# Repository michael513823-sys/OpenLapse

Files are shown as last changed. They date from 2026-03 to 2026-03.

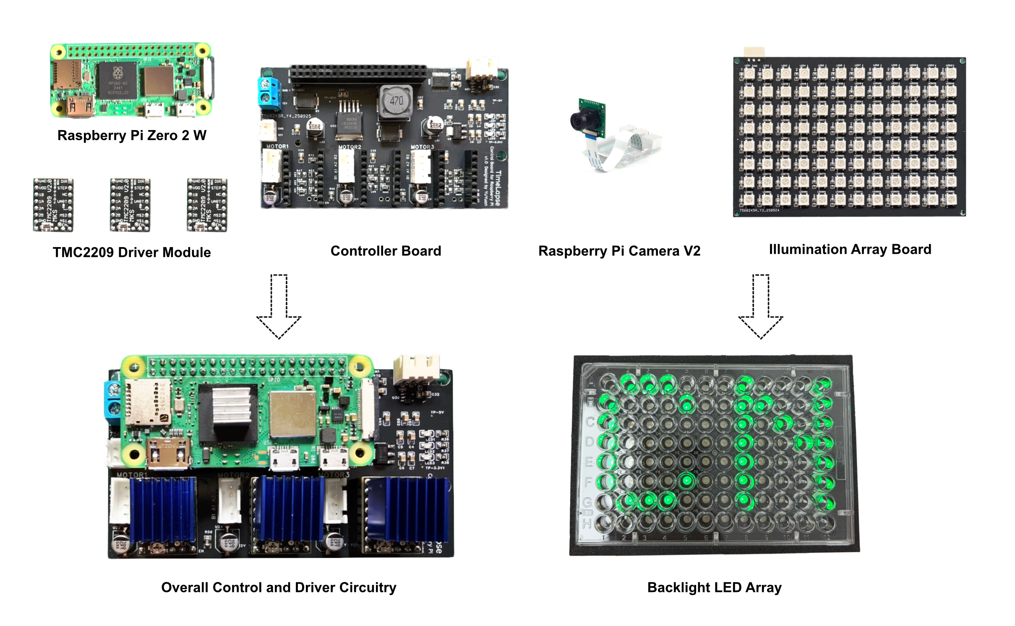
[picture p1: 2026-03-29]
imgs/Figure4.tiff

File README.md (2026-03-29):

# OpenLapse

OpenLapse is a DIY, low-cost, open-source in-incubator time-lapse imaging platform that combines 3D-printed mechanics, custom PCBs, and Python control software on both a Raspberry Pi and a desktop GUI.

## English

### Overview
- Reproducible, open-source platform for live-cell and embryo time-lapse imaging inside standard incubators.
- Modular hardware (controller PCB, illumination PCB, 3D-printed frame) plus two software layers: Raspberry Pi control (embedded) and desktop GUI (controller).
- Supports bright-field and oblique illumination and multiple well-plate formats (6/12/24/96).

### System Architecture
- PC GUI (OpenLapse-Controller) orchestrates experiment setup, well selection, scheduling, and monitoring.
- Raspberry Pi (OpenLapse-Embedded) drives motion, illumination, focus, and image capture/streaming.
- Communication over LAN: UDP broadcast for discovery/heartbeat, TCP for commands and acknowledgements.

```
PC (Controller) ⇄ TCP commands + preview ⇄ Raspberry Pi (Embedded)
                                 ⇵ UDP discovery/heartbeat
                          Motors / LEDs / Camera inside incubator
```

### Repository Structure
- [Controller/](Controller/) – Desktop GUI (Python + CustomTkinter); entry point [Controller/app.py](Controller/app.py); helper modules in [Controller/libs/](Controller/libs/); plate backgrounds in [Controller/plates/](Controller/plates/).
- [Raspi/](Raspi/) – Raspberry Pi embedded control software; entry point [Raspi/app.py](Raspi/app.py); device drivers and controllers in [Raspi/libs/](Raspi/libs/); configuration in [Raspi/config.py](Raspi/config.py); supplemental notes in [Raspi/doc/](Raspi/doc/).
- [PCB/](PCB/) – Controller board and illumination array board design/manufacturing files (Gerber, BOM, etc.).
- [STL_files/](STL_files/) – 3D-printable mechanical parts; use provided STLs (and optional slicing files if present) to fabricate the frame and fixtures.
- [imgs/](imgs/) – Photos, renders, and assembly/usage illustrations for documentation.

### Quick Start (print → assemble → install → run)
1) **Print**: Fabricate mechanical parts from [STL_files/](STL_files/) using PLA/PETG per your incubator environment; verify tolerances for motion axes.
2) **PCBs**: Order/fabricate controller and LED array boards from [PCB/](PCB/); gather BOM components and headers; follow hardware images in [imgs/](imgs/).
3) **Assemble**: Mount steppers, camera, and LED array to the printed frame; wire motors, UART, and LED data to the PCB; ensure stable 5 V supply; place the assembly in the incubator.
4) **Install Software**:
   - Desktop GUI: Python 3.9+, install dependencies from [Controller/README.md](Controller/README.md), then run [Controller/app.py](Controller/app.py).
   - Raspberry Pi: Raspberry Pi OS Lite, enable camera and UART, install dependencies from [Raspi/README.md](Raspi/README.md), then run [Raspi/app.py](Raspi/app.py).
5) **Run**: Connect PC and Pi to the same LAN; start the Pi service, then launch the GUI, auto-discover/connect, home axes, configure wells/illumination, and start time-lapse acquisition.

### Hardware
- **PCBs**: Controller board for TMC2209 stepper drivers, UART/GPIO, and LED array control; illumination array board (WS2812-based). Manufacturing files and BOMs are under [PCB/](PCB/). Verify motor current, stallguard homing, and thermal management inside incubators.
- **3D Printing**: Mechanical STLs in [STL_files/](STL_files/) for stage, camera mount, and structural parts; print with sufficient rigidity and heat tolerance. Optional slicing/3MF files may be included alongside STLs when available.

### Software
- **OpenLapse-Controller (Desktop)**: Python GUI for experiment setup, preview, manual XYZ control, well selection, scheduling, lighting, and autofocus. See [Controller/app.py](Controller/app.py) and supporting modules in [Controller/libs/](Controller/libs/).
- **OpenLapse-Embedded (Raspberry Pi)**: Headless control loop for motion, camera capture/streaming, illumination, and network commands. See [Raspi/app.py](Raspi/app.py), drivers in [Raspi/libs/](Raspi/libs/), and configuration in [Raspi/config.py](Raspi/config.py).

### Documentation and Images
- Photos, diagrams, and assembly references are in [imgs/](imgs/).
- Additional device notes and driver references reside in [Raspi/doc/](Raspi/doc/).

### Licensing Overview
- Hardware (PCBs, mechanical designs) is released under CERN Open Hardware License v2 Strongly Reciprocal (CERN-OHL-S-2.0). If you distribute modified hardware designs or manufactured hardware, you must also share the corresponding design source under the same license.
- Software (controller + embedded code) is released under the MIT License. You may use, modify, and redistribute the software, including in proprietary products, provided you keep the copyright notice and license terms.

### License
- **Hardware scope**: PCB design files (Controller Board, Illumination Array Board) and 3D models (STL/printing assets) are covered by CERN-OHL-S-2.0. See the full text: https://ohwr.org/cern_ohl_s_v2.txt
- **Software scope**: OpenLapse-Controller (desktop GUI) and OpenLapse-Embedded (Raspberry Pi backend) are covered by the MIT License. See the full text: https://opensource.org/license/mit
- **Reuse encouragement**: Please fork, adapt, and iterate. For hardware derivatives, publish your design source; for software, retain the copyright and license notice.

### Citation / Attribution
- For academic use, please cite the associated JoVE article (link forthcoming) and reference this repository (OpenLapse). Attribution helps trace reproducibility and improvements.

### Reproducibility & Open Science
- Designs, code, and documentation are open to enable replication and modification. Contributions should include build parameters, calibration steps, and configuration changes to help others reproduce results.

### Publication
- Associated Journal of Visualized Experiments (JoVE) article: add link here when available.

### Contributing
- Issues and pull requests are welcome. Please include reproducible build/assembly notes, calibration steps, and configuration changes so others can replicate results.

---

## 中文

### 项目概述
- 开源、低成本的培养箱内长时程成像平台，整合自制 PCB、3D 打印结构和树莓派 + 桌面端的 Python 控制软件。
- 支持多孔板格式（6/12/24/96），提供明场与斜射照明，可在培养箱内长期采集。

### 系统架构
- 桌面端 GUI（OpenLapse-Controller）负责实验配置、孔板选择、调度与监控。
- 树莓派端（OpenLapse-Embedded）负责电机、光源、对焦与图像采集/推流。
- 局域网通信：UDP 广播用于发现与心跳，TCP 传输命令与确认。

```
PC（上位机） ⇄ TCP 命令/预览 ⇄ 树莓派（嵌入端）
                          ⇵ UDP 发现与心跳
                 电机 / LED / 相机（位于培养箱内）
```

### 仓库结构
- [Controller/](Controller/) – 桌面端 GUI（Python + CustomTkinter）；入口 [Controller/app.py](Controller/app.py)；功能模块位于 [Controller/libs/](Controller/libs/)；孔板背景在 [Controller/plates/](Controller/plates/)。
- [Raspi/](Raspi/) – 树莓派嵌入式控制软件；入口 [Raspi/app.py](Raspi/app.py)；驱动与控制在 [Raspi/libs/](Raspi/libs/)；配置在 [Raspi/config.py](Raspi/config.py)；补充文档在 [Raspi/doc/](Raspi/doc/)。
- [PCB/](PCB/) – 控制板与照明阵列板的设计与生产文件（Gerber、BOM 等）。
- [STL_files/](STL_files/) – 3D 打印零件（结构、相机/电机安装件等）；如有附带切片文件可直接使用。
- [imgs/](imgs/) – 照片、渲染与装配示意图。

### 快速开始（打印 → 装配 → 安装 → 运行）
1) **打印**：使用 [STL_files/](STL_files/) 中的模型打印结构件（建议 PLA/PETG，依据培养箱环境选择），确认运动部件配合公差。
2) **制板**：从 [PCB/](PCB/) 获取 Gerber/BOM 进行下单，准备元件与接插件，结合 [imgs/](imgs/) 进行焊接与检查。
3) **装配**：安装步进电机、相机与 LED 阵列至打印结构，连接电机、UART 与 LED 数据线，确保稳定 5 V 供电后放入培养箱。
4) **安装软件**：
   - 桌面端：按 [Controller/README.md](Controller/README.md) 安装 Python 依赖，运行 [Controller/app.py](Controller/app.py)。
   - 树莓派：按 [Raspi/README.md](Raspi/README.md) 配置系统与依赖，运行 [Raspi/app.py](Raspi/app.py)。
5) **运行**：让 PC 与树莓派处于同一局域网，先启动树莓派服务，再启动 GUI，自动发现并连接后完成回零、孔板/光照配置并开始时间序列采集。

### 硬件
- **PCB**：控制板集成 TMC2209 步进驱动、UART/GPIO 与 LED 阵列控制；照明阵列板基于 WS2812。生产文件在 [PCB/](PCB/)；请在培养箱环境下关注电流设定、stallguard 归零与散热。
- **3D 打印**：结构与安装件位于 [STL_files/](STL_files/)；选择足够刚性的材料并考虑温度耐受性；如有提供切片文件可直接使用。

### 软件
- **OpenLapse-Controller（桌面端）**：实验配置、预览、手动 XYZ 控制、孔板选择、调度、光源与自动对焦。参考 [Controller/app.py](Controller/app.py) 及 [Controller/libs/](Controller/libs/)。
- **OpenLapse-Embedded（树莓派）**：电机、相机采集/推流、照明与网络命令处理。参考 [Raspi/app.py](Raspi/app.py)、[Raspi/libs/](Raspi/libs/) 以及 [Raspi/config.py](Raspi/config.py)。

### 文档与图片
- 装配与使用图片位于 [imgs/](imgs/)。
- 设备说明与驱动参考在 [Raspi/doc/](Raspi/doc/)。

### 许可证
- **硬件**（PCB、机械设计）：CERN-OHL-S-2.0。
- **软件**（上位机与嵌入式代码）：MIT License。

### 论文
- 相关 JoVE 论文：发布后在此添加链接。

### 贡献
- 欢迎提交 Issue/PR，并附带可复现的装配、校准与配置说明，便于社区复现与改进。

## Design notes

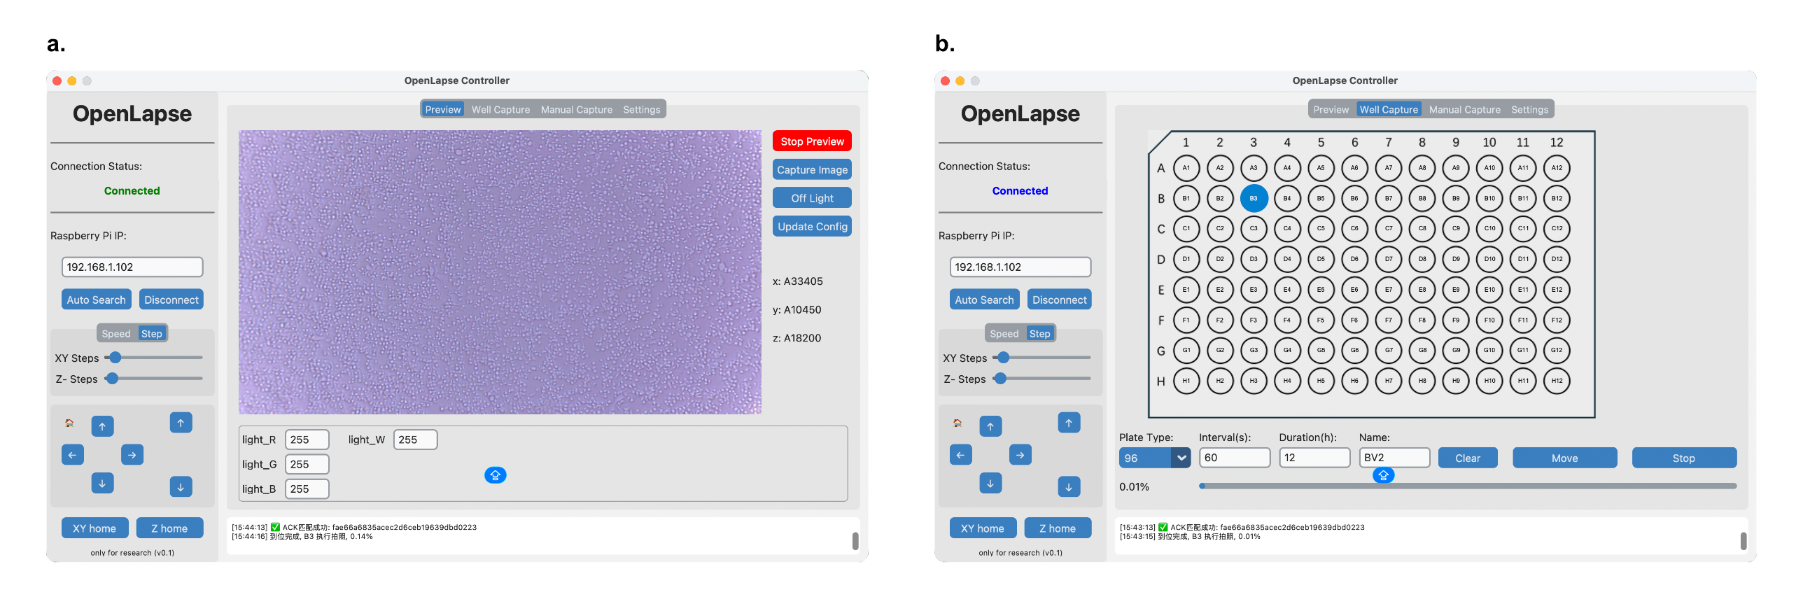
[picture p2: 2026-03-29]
imgs/Figure5.tiff

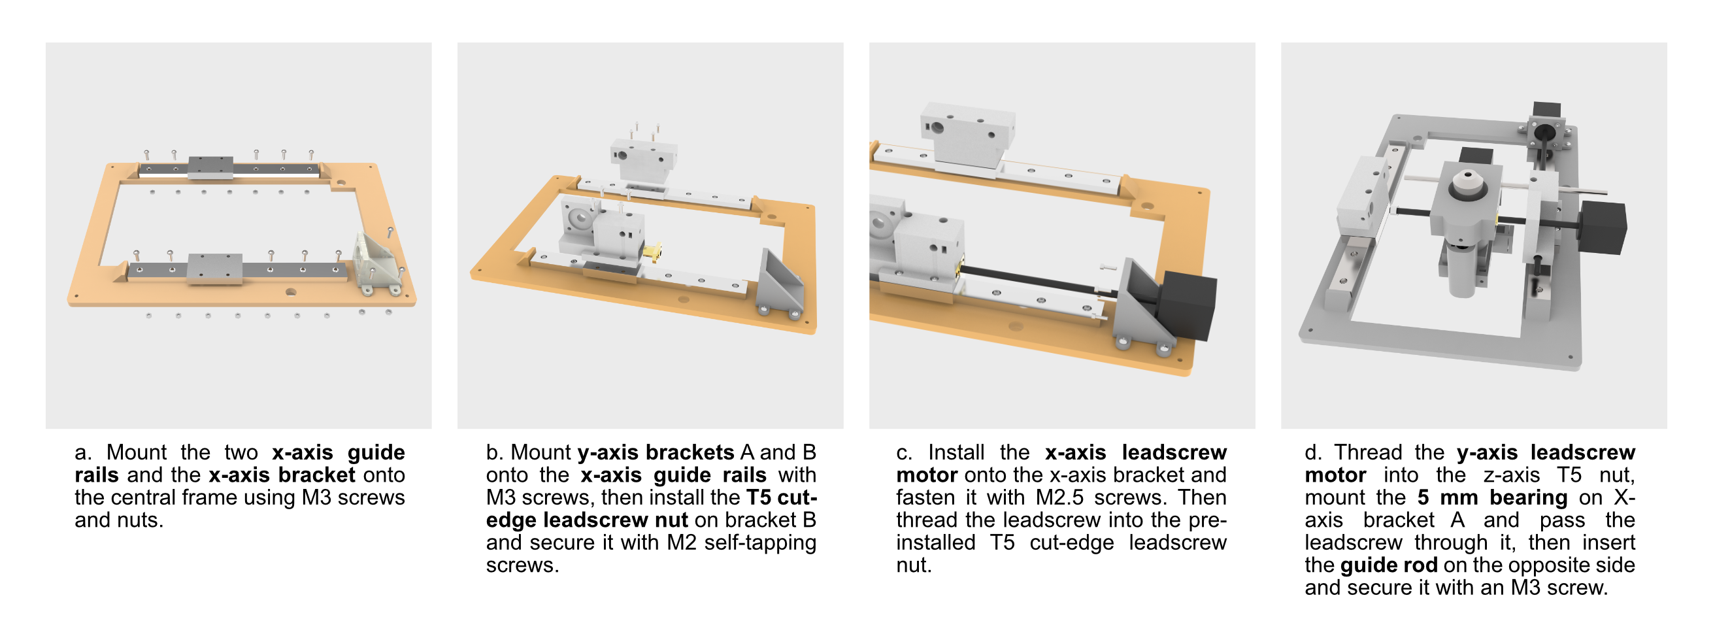
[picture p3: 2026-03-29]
imgs/Figure2.tiff

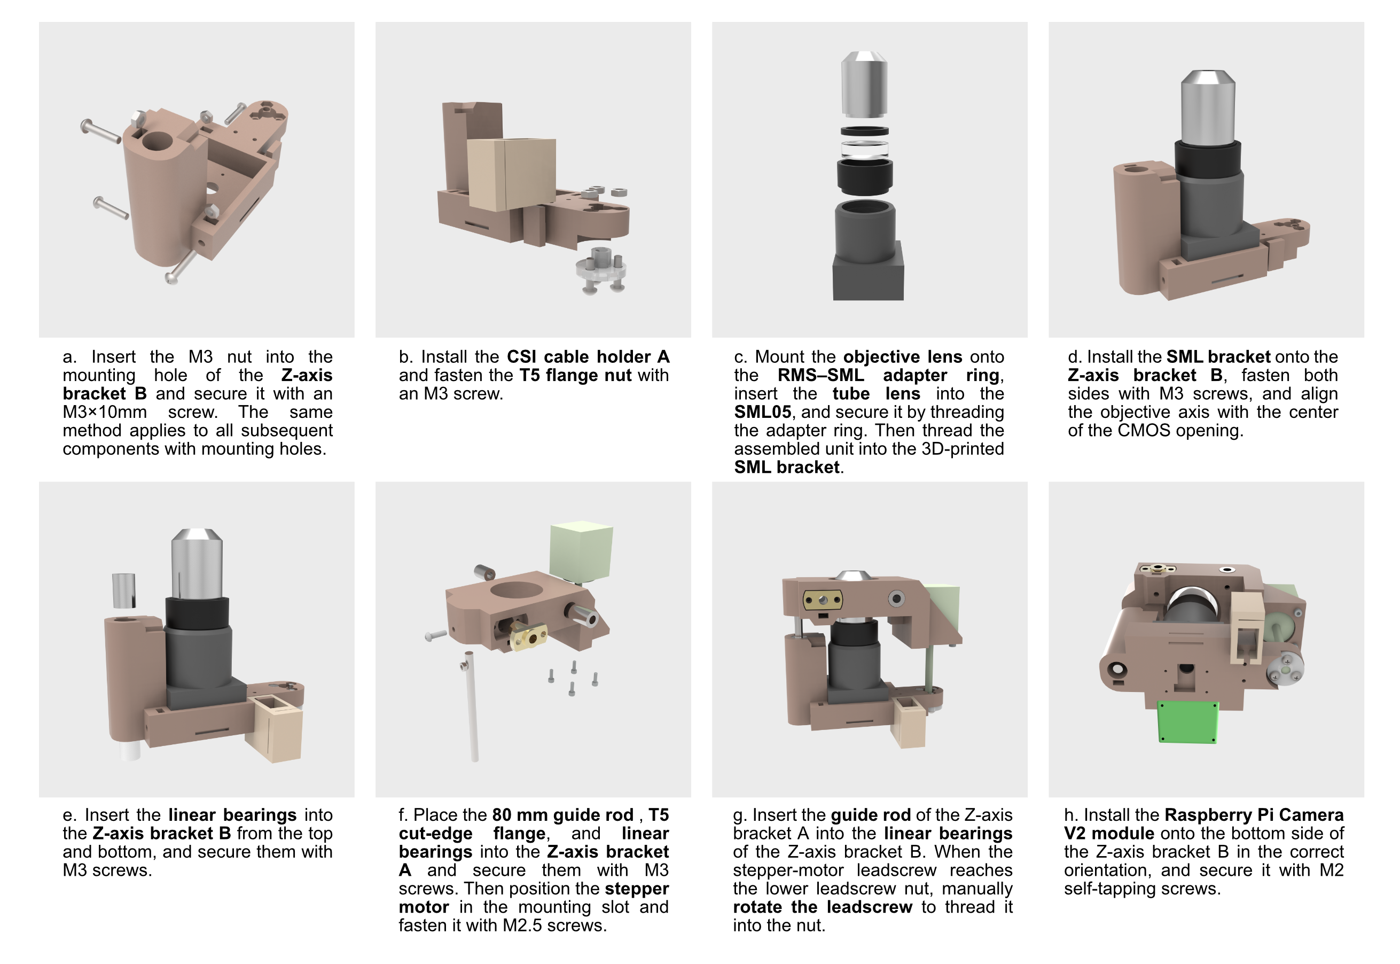
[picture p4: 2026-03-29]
imgs/Figure1.tiff

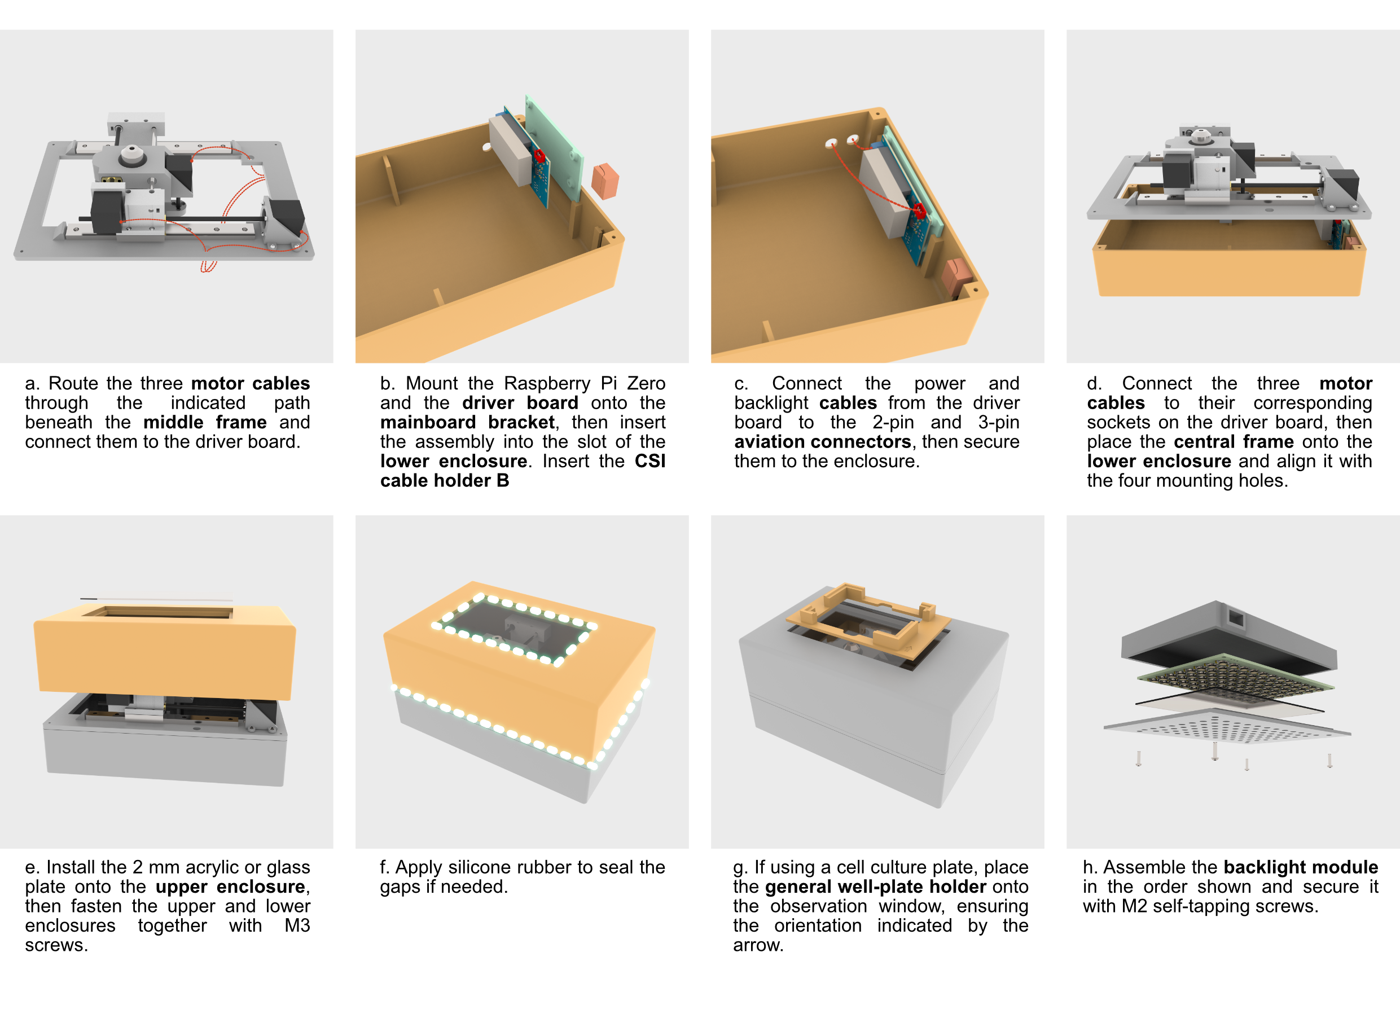
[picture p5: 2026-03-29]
imgs/Figure3.tiff

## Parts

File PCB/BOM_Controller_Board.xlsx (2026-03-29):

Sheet: bom模板
 |  |  |  | Bill of Materials | BOM_主控板_2w_Schematic3_2026-03-29
 |  |  |  | Project Title： | 时差培养箱
 |  |  |  | Variant:
 |  |  |  | Report Time： | 2026年3月29日 17:0:41
No. | Quantity | Comment | Designator | Footprint | Value | Manufacturer Part | Manufacturer | Supplier Part | Supplier | LCSC Price | Total
 | 3 | 10uF | C4, C6, C50 | C0805 | 10uF | CL21A106KOQNNNE | SAMSUNG(三星) | C1713 | LCSC
 | 8 | 100nF | C5, C7, C29, C30, C31, C32, C33, C51 | C0805 | 100nF | FCC0805B104K500DT | FOJAN(富捷) | C5137467 | LCSC
 | 3 | 1uF | C49, C52, C53 | C0805 | 1uF | CL21B105KBFNNNE | SAMSUNG(三星) | C28323 | LCSC
 | 1 | 33nF | C54 | C0805 | 33nF | CC0805KRX7R9BB333 | YAGEO(国巨) | C107150 | LCSC
 | 1 | ZX-XH2.54-3PWZ-GW | CN1 | CONN-TH_ZX-XH2.54-3PWZ-R |  | ZX-XH2.54-3PWZ-GW | Megastar(兆星) | C42441539 | LCSC
 | 1 | KF301-5.0-2P | CN29 | CONN-TH_P5.00_KF301-5.0-2P |  | KF301-5.0-2P | KEFA(科发) | C474881 | LCSC
 | 1 | XH2.54*2P_直插 | CN30 | CONN-TH_2P-P2.50-XH2.54-2P |  | XH2.54*2P_直插 |  | C9900008615 | LCSC
 | 2 | SS1045 | D7, D8 | SMC_L6.9-W5.9-LS7.9-RD |  | SS1045 | LGE(鲁光) | C2903779 | LCSC
 | 1 | 47uH | L1 | IND-SMD_L12.3-W12.3 | 47uH | SMDRI127-470MT | SXN(顺翔诺) | C9906 | LCSC
 | 3 | YLED0805B | LED1, LED2, LED3 | LED0805-RD |  | YLED0805B | YONGYUTAI(永裕泰) | C19273154 | LCSC
 | 3 | XH2.54_4P_直插 | MOTOR1, MOTOR2, MOTOR3 | CONN-TH_4P-P2.50-XH2.54-4P |  | XH2.54_4P_直插 |  | C9900008616 | LCSC
 | 1 | 10kΩ | R23 | R0805 | 10kΩ | FRC0805J103TS | FOJAN(富捷) | C2930231 | LCSC
 | 1 | 3.3kΩ | R24 | R0805 | 3.3kΩ | 0805W8F3301T5E | UNI-ROYAL(厚声) | C26010 | LCSC
 | 1 | 4.7kΩ | R36 | R0805 | 4.7kΩ | 0805W8F4701T5E | UNI-ROYAL(厚声) | C17673 | LCSC
 | 1 | 2.2kΩ | R37 | R0805 | 2.2kΩ | 0805W8F2201T5E | UNI-ROYAL(厚声) | C17520 | LCSC
 | 2 | 1kΩ | R38, R73 | R0805 | 1kΩ | 0805W8F1001T5E | UNI-ROYAL(厚声) | C17513 | LCSC
 | 22 | 10kΩ | R47, R48, R49, R53, R54, R55, R56, R57, R58, R59, R60, R61, R62, R63, R64, R65, R66, R67, R68, R70, R71, R72 | R0805 | 10kΩ | 0805W8F1002T5E | UNI-ROYAL(厚声) | C17414 | LCSC
 | 1 | 2.54-2*20 | RPi_GPIO | HDR-TH_40P-P2.54-V-F-R2-C20-S2.54 |  | 2.54-2*20 | ZHOURI(洲日) | C2977589 | LCSC
 | 4 | Test-Point | TP-3.3V1, TP-5V, TP-12V1, TP-GND1 | Test-Point-0.5mm
 | 1 | AMS1117-5.0 | U3 | SOT-223_L6.5-W3.5-P2.30-LS7.0-BR |  | AMS1117-5.0 | AMS | C6187 | LCSC
 | 3 | 100uF贴片电解 | U22, U24, U26 | CAP-SMD_BD6.3-L6.6-W6.6-LS7.4-FD |  | 100uF贴片电解 |  | C9900002196 | LCSC
 | 3 | TMC2209SILENTSTEPSTICK | U23, U25, U27 | COMM-TH_TMC2209SILENTSTEPSTICK |  | TMC2209SILENTSTEPSTICK | TRINAMIC | C17375345 | LCSC
 | 1 | SN74HCT245PWR | U28 | TSSOP-20_L6.5-W4.4-P0.65-LS6.4-BL |  | SN74HCT245PWR | TI(德州仪器) | C6779 | LCSC
 | 1 | 74HCT1G125GV,125 | U30 | SOT-753_L3.1-W1.7-P0.95-LS3.0-BL |  | 74HCT1G125GV,125 | Nexperia(安世) | C12502 | LCSC
 | 1 | 330uF | U31 | CAP-SMD_BD6.3-L6.6-W6.6-LS7.3-FD | 330uF | JVJ25V330M6x8 | JIERR(捷而瑞) | C46550406 | LCSC
 | 1 | XL4015E1 | U32 | TO-263-5_L10.2-W8.9-P1.70-TL |  | XL4015E1 | XLSEMI(芯龙) | C51661 | LCSC
 | 1 | 220uF | U33 | CAP-SMD_BD6.3-L6.6-W6.6-LS7.3-FD-H7.7 | 220uF | JVJ25V220M6x8 | JIERR(捷而瑞) | C46550404 | LCSC

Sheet: Field汇总
Project Title | 时差培养箱
Borard Title | 主控板_2w
Schematic Title | Schematic3
PCB Title
Variant Name
Total Quantity | 72
Report Time | 17:0:41
Report Date | 2026年3月29日
Report Date&Time | 2026年3月29日 17:0:41
File Name | BOM_主控板_2w_Schematic3_2026-03-29
Filter Option | Add into BOM:no;

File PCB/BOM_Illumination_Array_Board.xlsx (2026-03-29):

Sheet: bom模板
 |  |  |  | Bill of Materials | BOM_背光板V2_PCB2_2026-03-29
 |  |  |  | Project Title： | 时差培养箱
 |  |  |  | Variant:
 |  |  |  | Report Time： | 2026年3月29日 17:1:16
No. | Quantity | Comment | Designator | Footprint | Value | Manufacturer Part | Manufacturer | Supplier Part | Supplier | LCSC Price | Total
 | 96 | 100nF | C1, C2, C3, C4, C5, C6, C7, C8, C9, C10, C11, C12, C13, C14, C15, C16, C17, C18, C19, C20, C21, C22, C23, C24, C25, C26, C27, C28, C29, C30, C31, C32, C33, C34, C35, C36, C37, C38, C39, C40, C41, C42, C43, C44, C45, C46, C47, C48, C49, C50, C51, C52, C53, C54, C55, C56, C57, C58, C59, C60, C61, C62, C63, C64, C65, C66, C67, C68, C69, C70, C71, C72, C73, C74, C75, C76, C77, C78, C79, C80, C81, C82, C83, C84, C85, C86, C87, C88, C89, C90, C91, C92, C93, C94, C95, C96 | C0805 | 100nF | FCC0805B104K500DT | FOJAN(富捷) | C5137467 | LCSC
 | 1 | ZX-XH2.54-3PWZ-GW | CN1 | CONN-TH_ZX-XH2.54-3PWZ-R |  | ZX-XH2.54-3PWZ-GW | Megastar(兆星) | C42441539 | LCSC
 | 96 | XL-5050RGBC-WS2812B | LED1, LED2, LED3, LED4, LED5, LED6, LED7, LED8, LED9, LED10, LED11, LED12, LED13, LED14, LED15, LED16, LED17, LED18, LED19, LED20, LED21, LED22, LED23, LED24, LED25, LED26, LED27, LED28, LED29, LED30, LED31, LED32, LED33, LED34, LED35, LED36, LED37, LED38, LED39, LED40, LED41, LED42, LED43, LED44, LED45, LED46, LED47, LED48, LED49, LED50, LED51, LED52, LED53, LED54, LED55, LED56, LED57, LED58, LED59, LED60, LED61, LED62, LED63, LED64, LED65, LED66, LED67, LED68, LED69, LED70, LED71, LED72, LED73, LED74, LED75, LED76, LED77, LED78, LED79, LED80, LED81, LED82, LED83, LED84, LED85, LED86, LED87, LED88, LED89, LED90, LED91, LED92, LED93, LED94, LED95, LED96 | LED-SMD_4P-L5.0-W5.0-BL_XL-5050RGBC |  | XL-5050RGBC-WS2812B | XINGLIGHT(成兴光) | C2843785 | LCSC

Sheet: Field汇总
Project Title | 时差培养箱
Borard Title | 背光板V2
Schematic Title
PCB Title | PCB2
Variant Name
Total Quantity | 193
Report Time | 17:1:16
Report Date | 2026年3月29日
Report Date&Time | 2026年3月29日 17:1:16
File Name | BOM_背光板V2_PCB2_2026-03-29
Filter Option | Add into BOM:no;

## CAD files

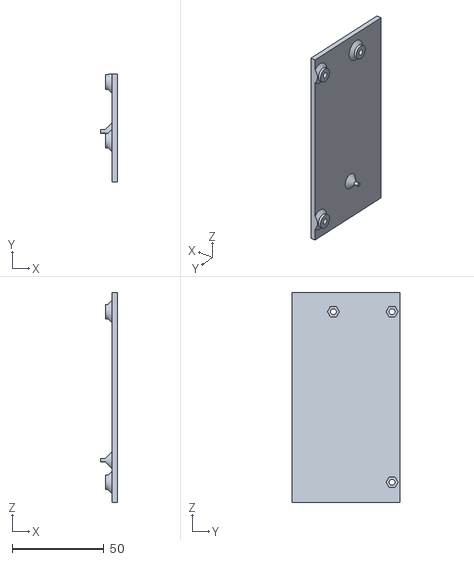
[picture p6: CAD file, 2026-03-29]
STL_files/3D-Print - mainboard_bracket.STL
9.00 x 59.0 x 114.5

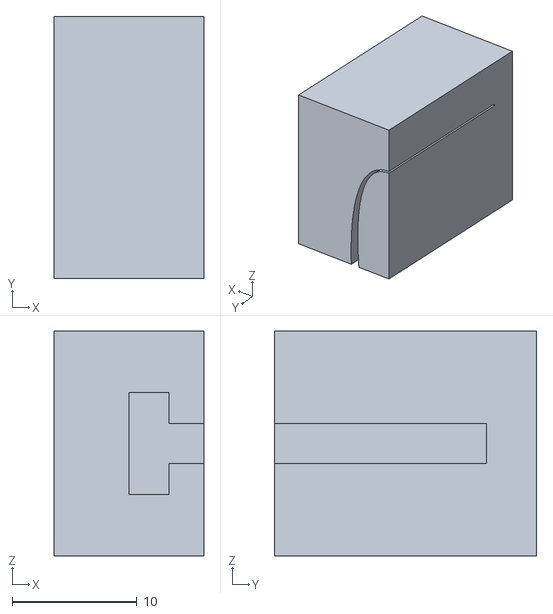
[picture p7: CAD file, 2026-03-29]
STL_files/3D-Print - csi_cable_holder_B.STL
12.0 x 21.0 x 18.0

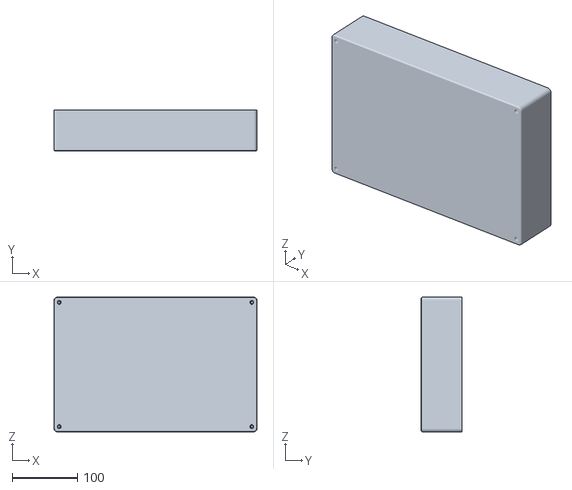
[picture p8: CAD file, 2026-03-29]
STL_files/3D-Print - enclosure_lower.STL
312.2 x 63.0 x 207.0

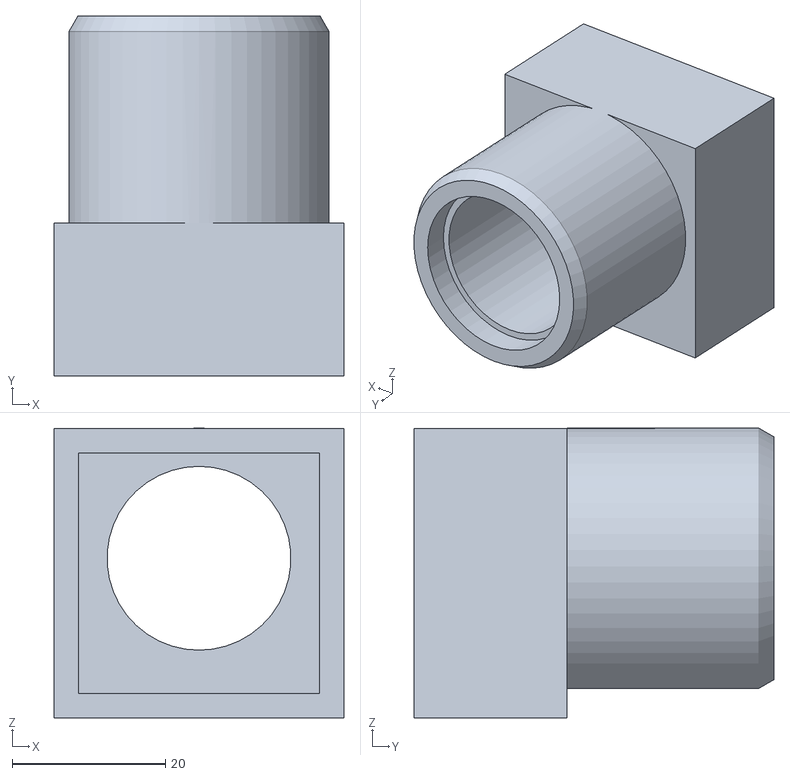
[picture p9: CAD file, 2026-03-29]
STL_files/3D-Print - SML_bracket.STL
37.8 x 47.0 x 37.8

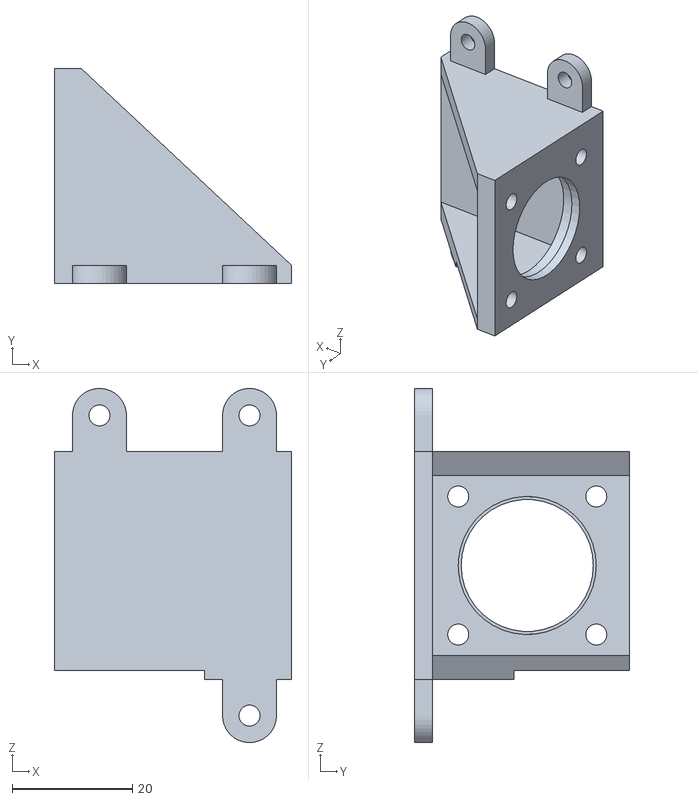
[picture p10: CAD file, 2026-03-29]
STL_files/3D-Print - x-axis_bracket.STL
39.5 x 35.8 x 59.0

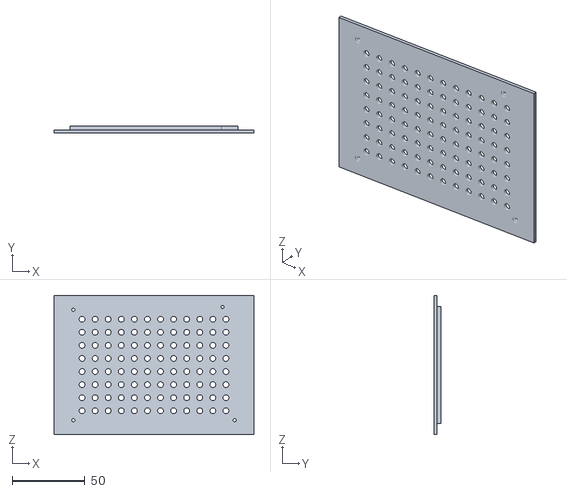
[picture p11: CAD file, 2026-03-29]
STL_files/3D-Print - light_shell_B.STL
137.6 x 4.50 x 95.8

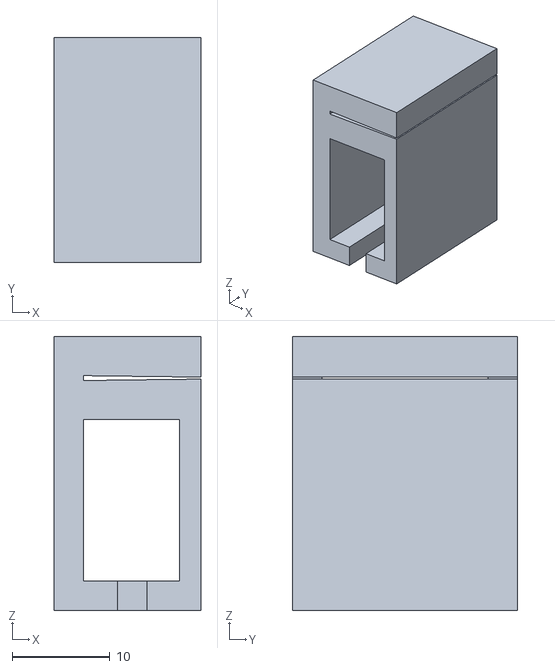
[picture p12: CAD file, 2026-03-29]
STL_files/3D-Print - csi_cable_holder_A.STL
15.0 x 23.0 x 28.0

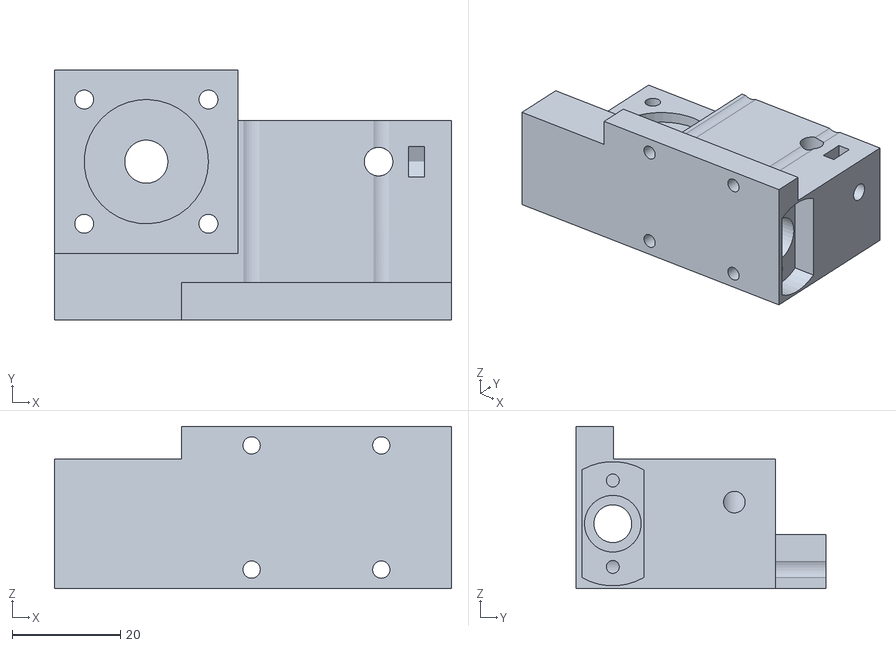
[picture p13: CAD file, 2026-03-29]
STL_files/3D-Print - y-axis_bracket_B.STL
73.5 x 46.3 x 30.0

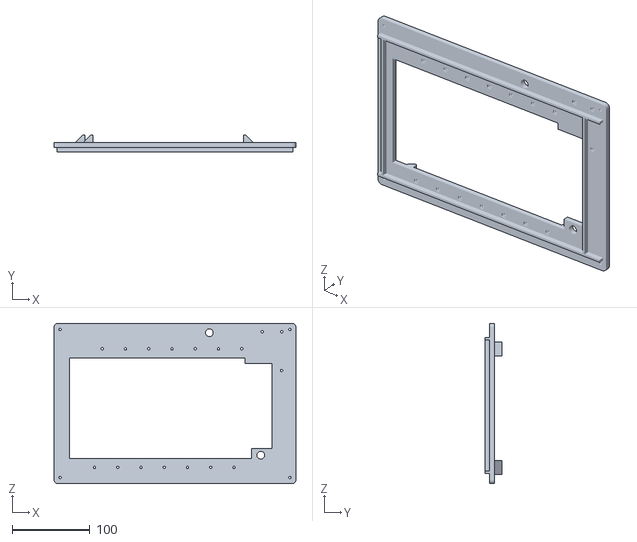
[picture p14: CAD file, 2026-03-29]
STL_files/3D-Print - middle_frame.STL
312.2 x 22.0 x 207.0

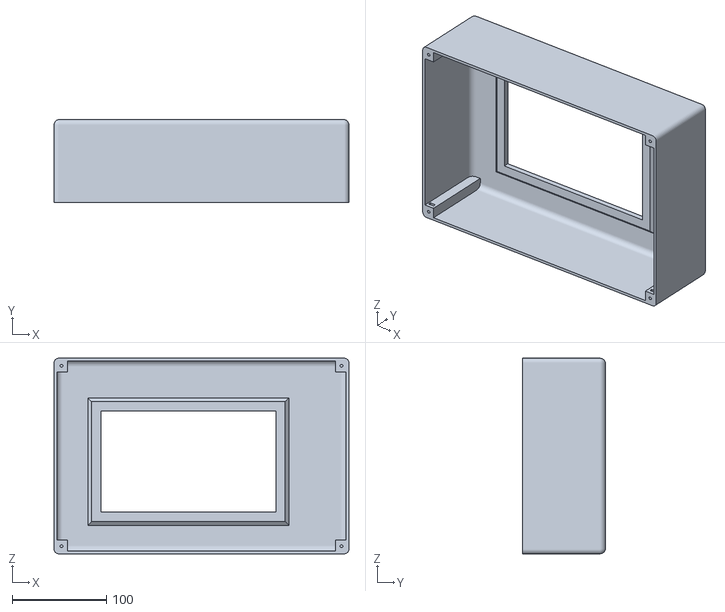
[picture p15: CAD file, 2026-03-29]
STL_files/3D-Print - enclosure_upper.STL
312.2 x 88.0 x 207.0

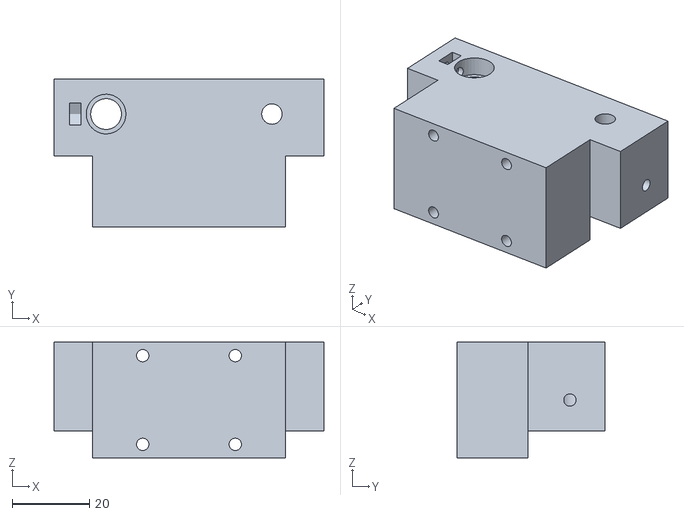
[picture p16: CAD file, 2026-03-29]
STL_files/3D-Print - y-axis_bracket_A.STL
70.0 x 38.5 x 30.0

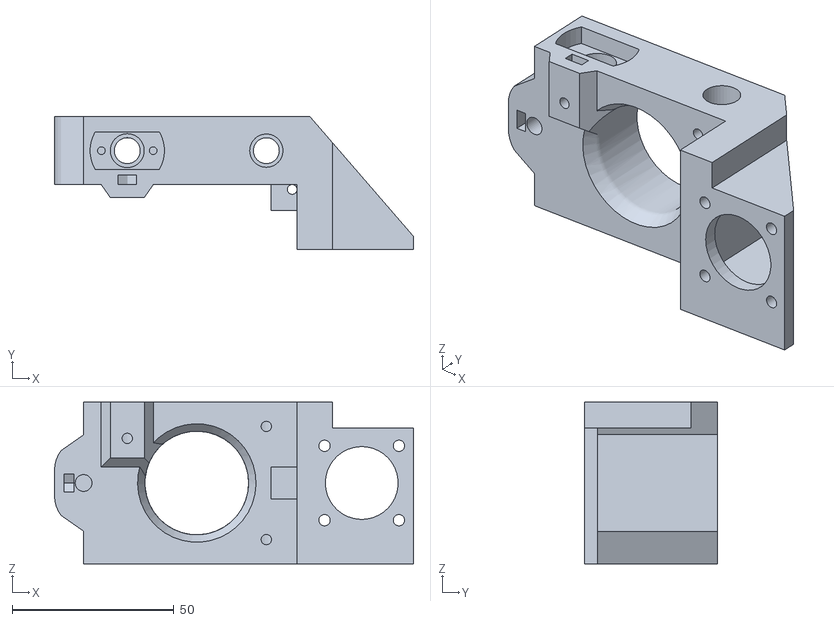
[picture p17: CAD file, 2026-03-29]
STL_files/3D-Print - z-axis_bracket_A.STL
111.0 x 41.0 x 50.0

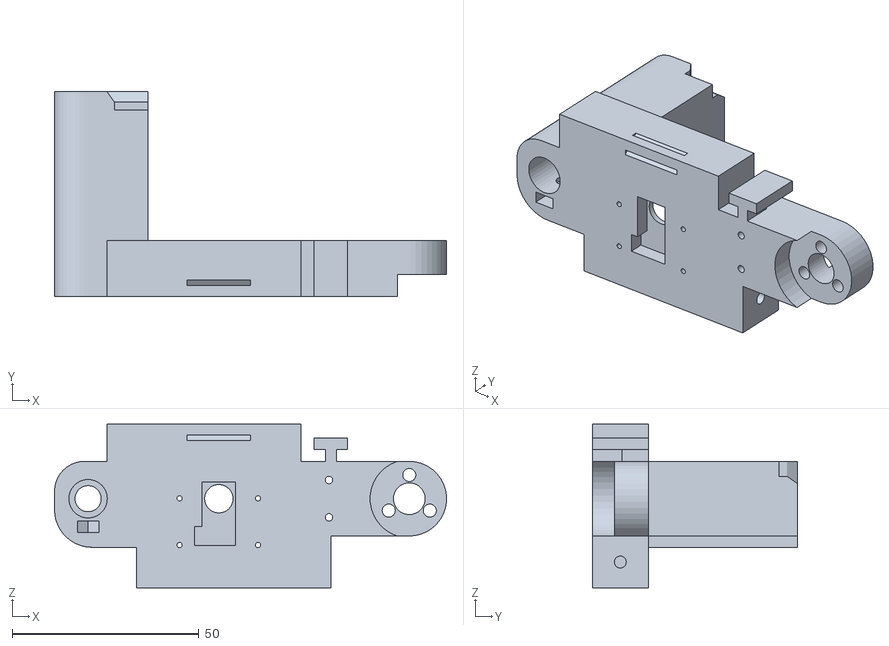
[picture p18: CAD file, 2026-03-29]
STL_files/3D-Print - z-axis_bracket_B.STL
105.0 x 55.0 x 43.9

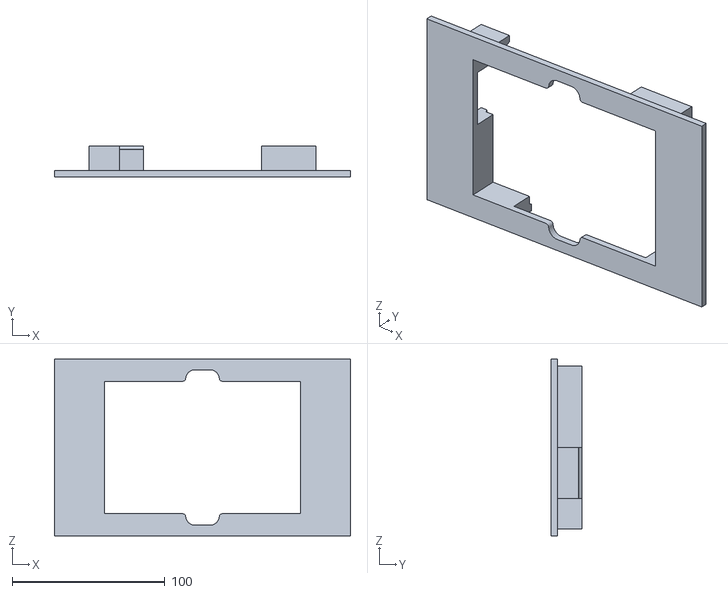
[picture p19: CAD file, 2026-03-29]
STL_files/3D-Print - general_well-plate_holder.STL
194.0 x 20.0 x 116.0

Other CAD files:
STL_files/3D-Print - light_shell_A.STL

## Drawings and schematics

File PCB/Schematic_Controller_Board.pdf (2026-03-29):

# Raspi

# LED

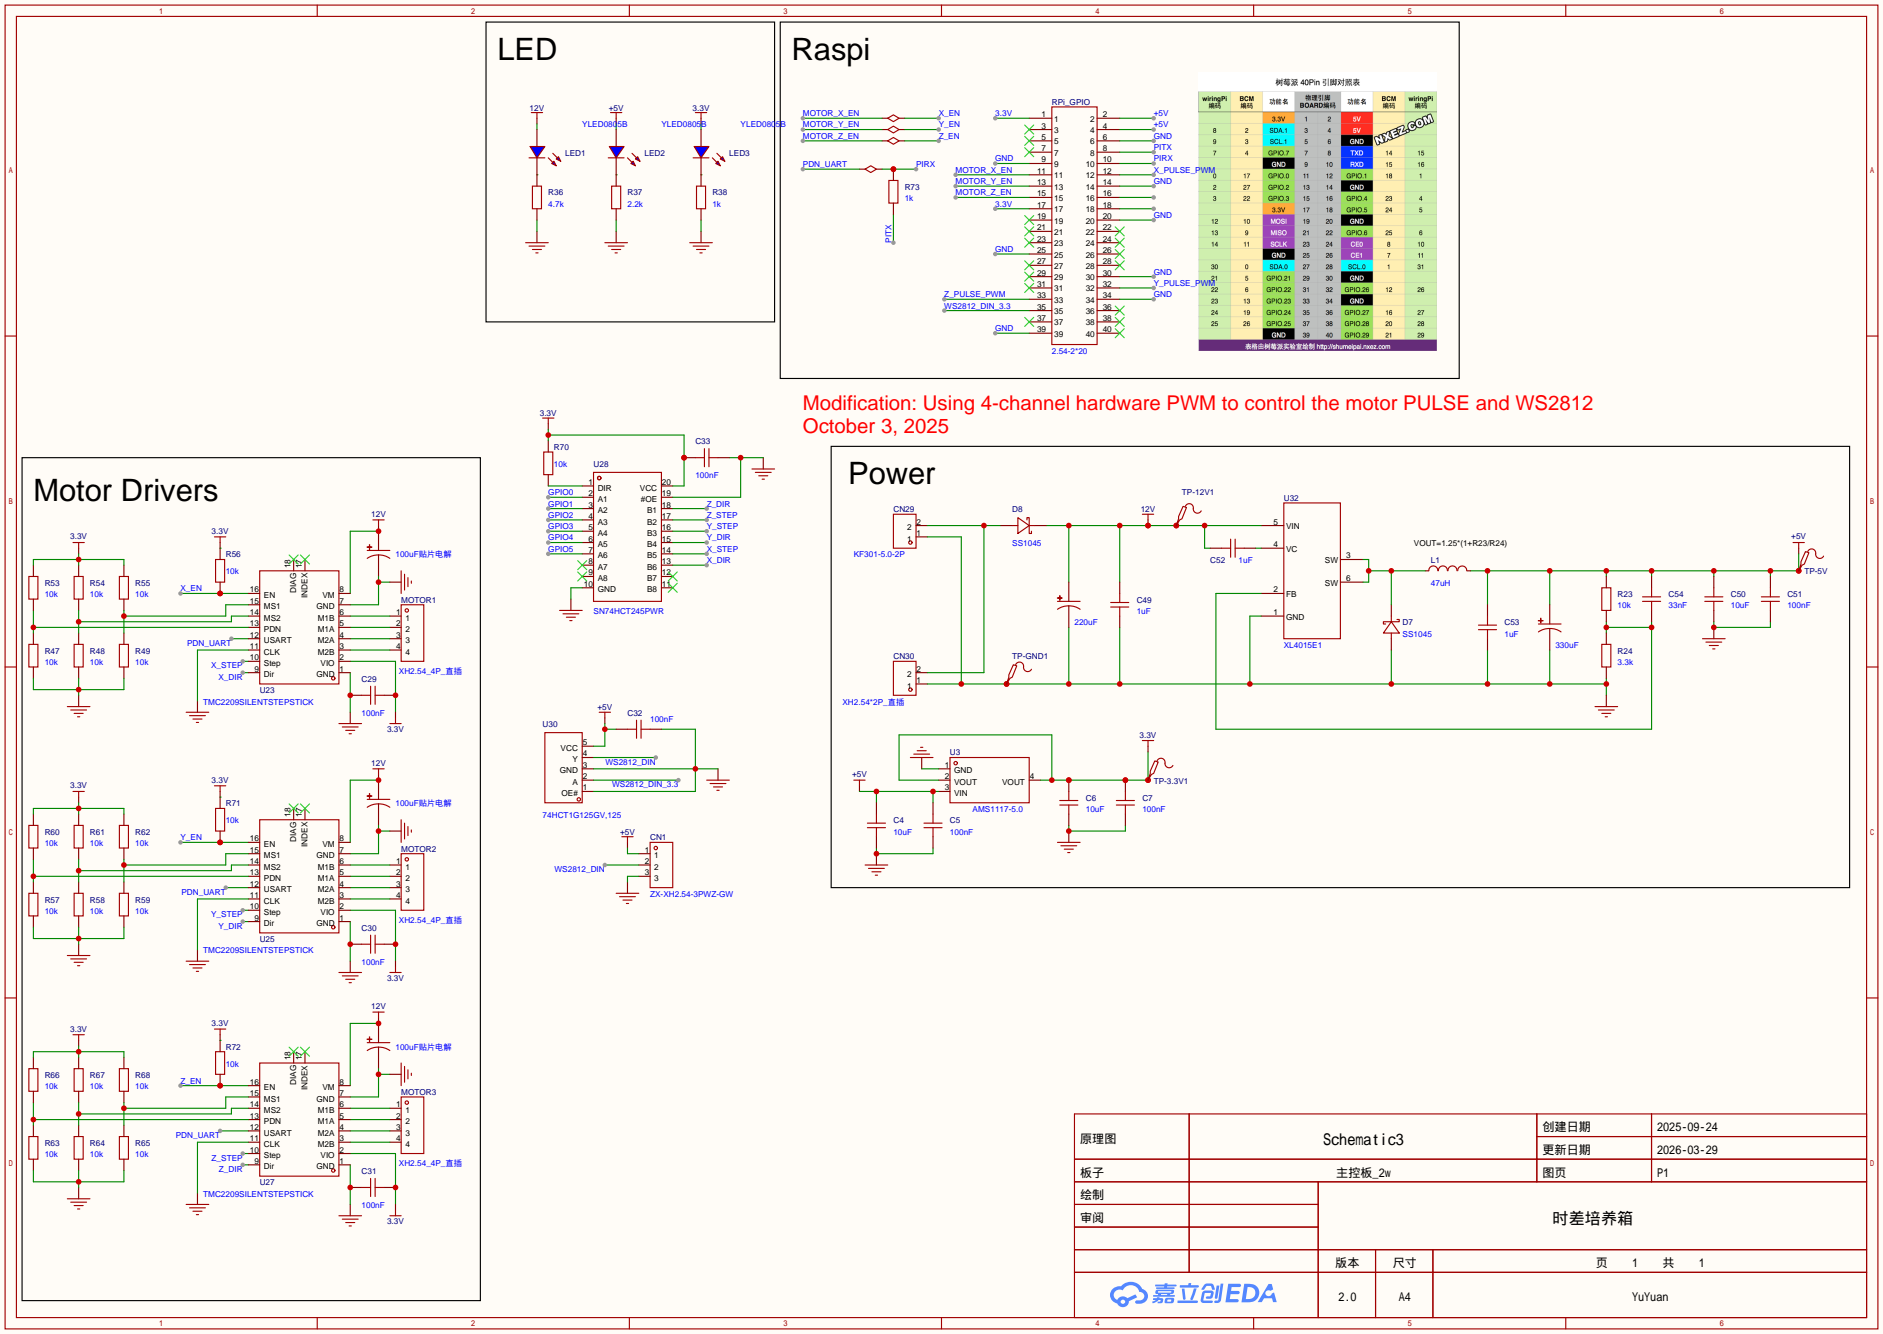
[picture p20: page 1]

Modification: Using 4-channel hardware PWM to control the motor PULSE and WS2812
October 3, 2025
Power

Step 10 CLK 11 USART 12 PDN 13 MS2 14 MS1 15 EN 16

原理图 | Schematic3 | 创建日期 | 2025-09-24

更新日期 | 2026-03-29

板子 | 主控板_2w | 图页 | P1

绘制 | | 时差培养箱
审阅

2.0 | A4 | YuYuan

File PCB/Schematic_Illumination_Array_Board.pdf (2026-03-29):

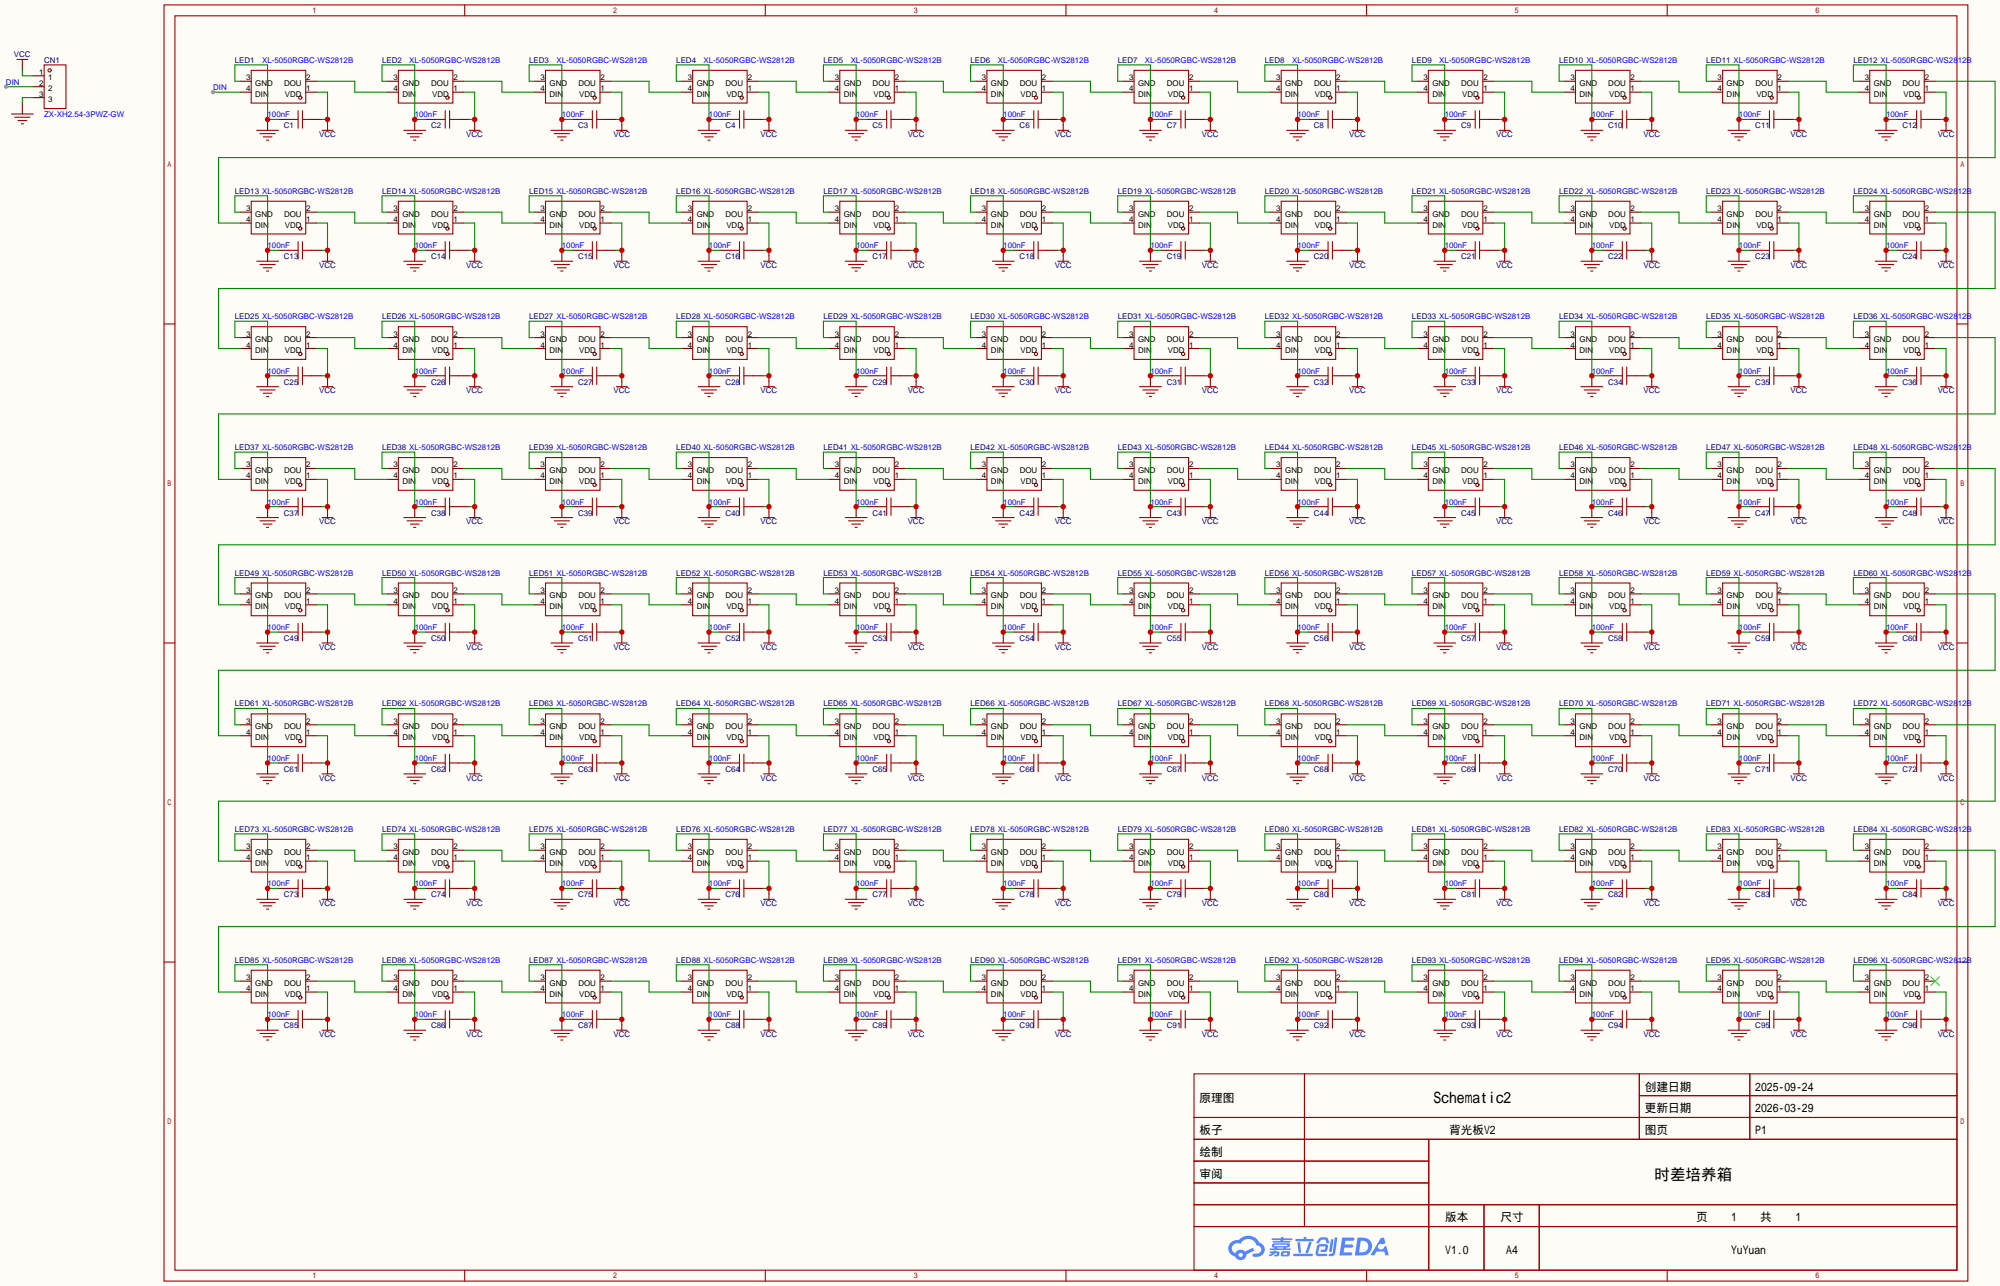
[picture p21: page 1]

原理图 | Schematic2 | 创建日期 | 2025-09-24

更新日期 | 2026-03-29

板子 | 背光板V2 | 图页 | P1

绘制 | | 时差培养箱
审阅

V1.0 | A4 | YuYuan
